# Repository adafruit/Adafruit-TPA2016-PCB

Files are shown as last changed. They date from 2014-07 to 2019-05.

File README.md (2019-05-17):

# Adafruit Stereo 2.8W Class D Audio Amplifier TPA2016 PCB
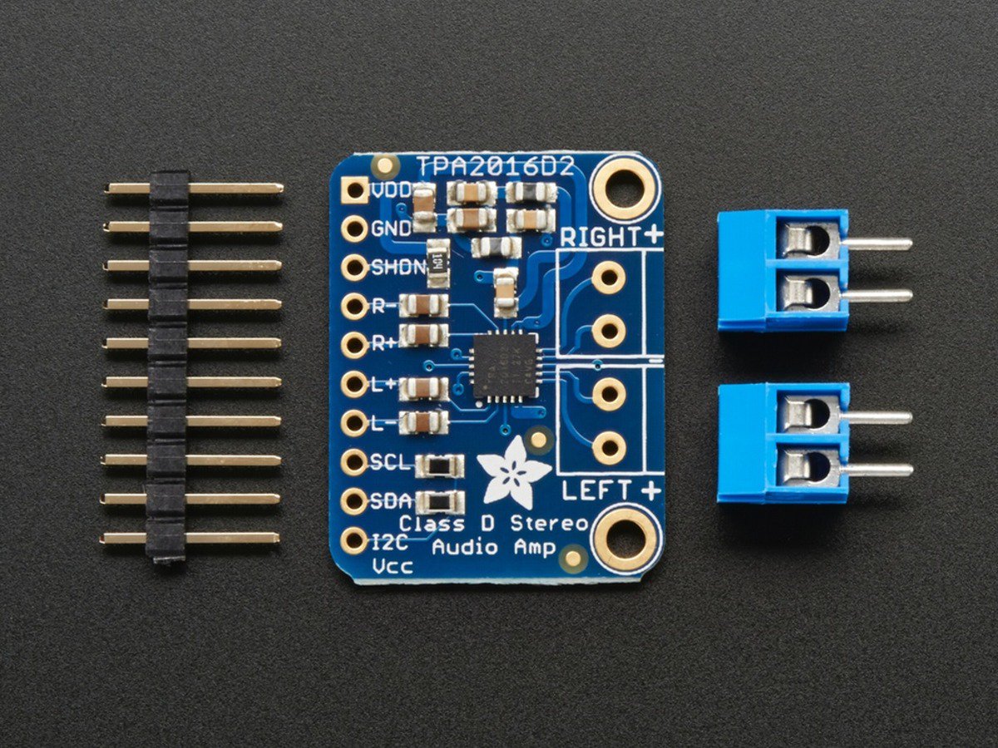
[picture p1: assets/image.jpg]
<a href="http://www.adafruit.com/products/1712"><br/>
Click here to purchase one from the Adafruit shop</a>

A mini class D with AGC and I2C control? Yes please! This incredibly small stereo amplifier is surprisingly powerful. It is able to deliver 2 x 2.8W channels into 4 ohm impedance speakers (@ 10% THD) and it has a i2c control interface as well as an AGC (automatic gain control) system to keep your audio from clipping or distorting.

If you don't want to use I2C to control it, it does start up on with 6dB gain by default and the AGC set up for most music playing. We do suggest using it with a microcontroller to configure it, however, since its quite powerful. Settings are not stored in the chip, so you'll need to adjust any gain & AGC amplification settings every time the amp is powered up.

Inside the miniature chip is a class D controller, able to run from 2.7V-5.5VDC. Since the amp is a class D, it's incredibly efficient (89% efficient when driving an 8Ω speaker at 1.5 Watt) - making it perfect for portable and battery-powered projects. It has built in thermal and over-current protection but we could barely tell if it got hot. This board is a welcome upgrade to basic "LM386" amps!

PCB files for Adafruit TPA2016 I2C Audio Amplifier PCB. The format is EagleCAD schematic and board layout: https://www.adafruit.com/products/1712

### License

Adafruit invests time and resources providing this open source design, please support Adafruit and open-source hardware by purchasing products from [Adafruit](https://www.adafruit.com)!

All text above must be included in any redistribution

Designed by Limor Fried/Ladyada for Adafruit Industries.
Creative Commons Attribution/Share-Alike, all text above must be included in any redistribution. 
See license.txt for additional information.

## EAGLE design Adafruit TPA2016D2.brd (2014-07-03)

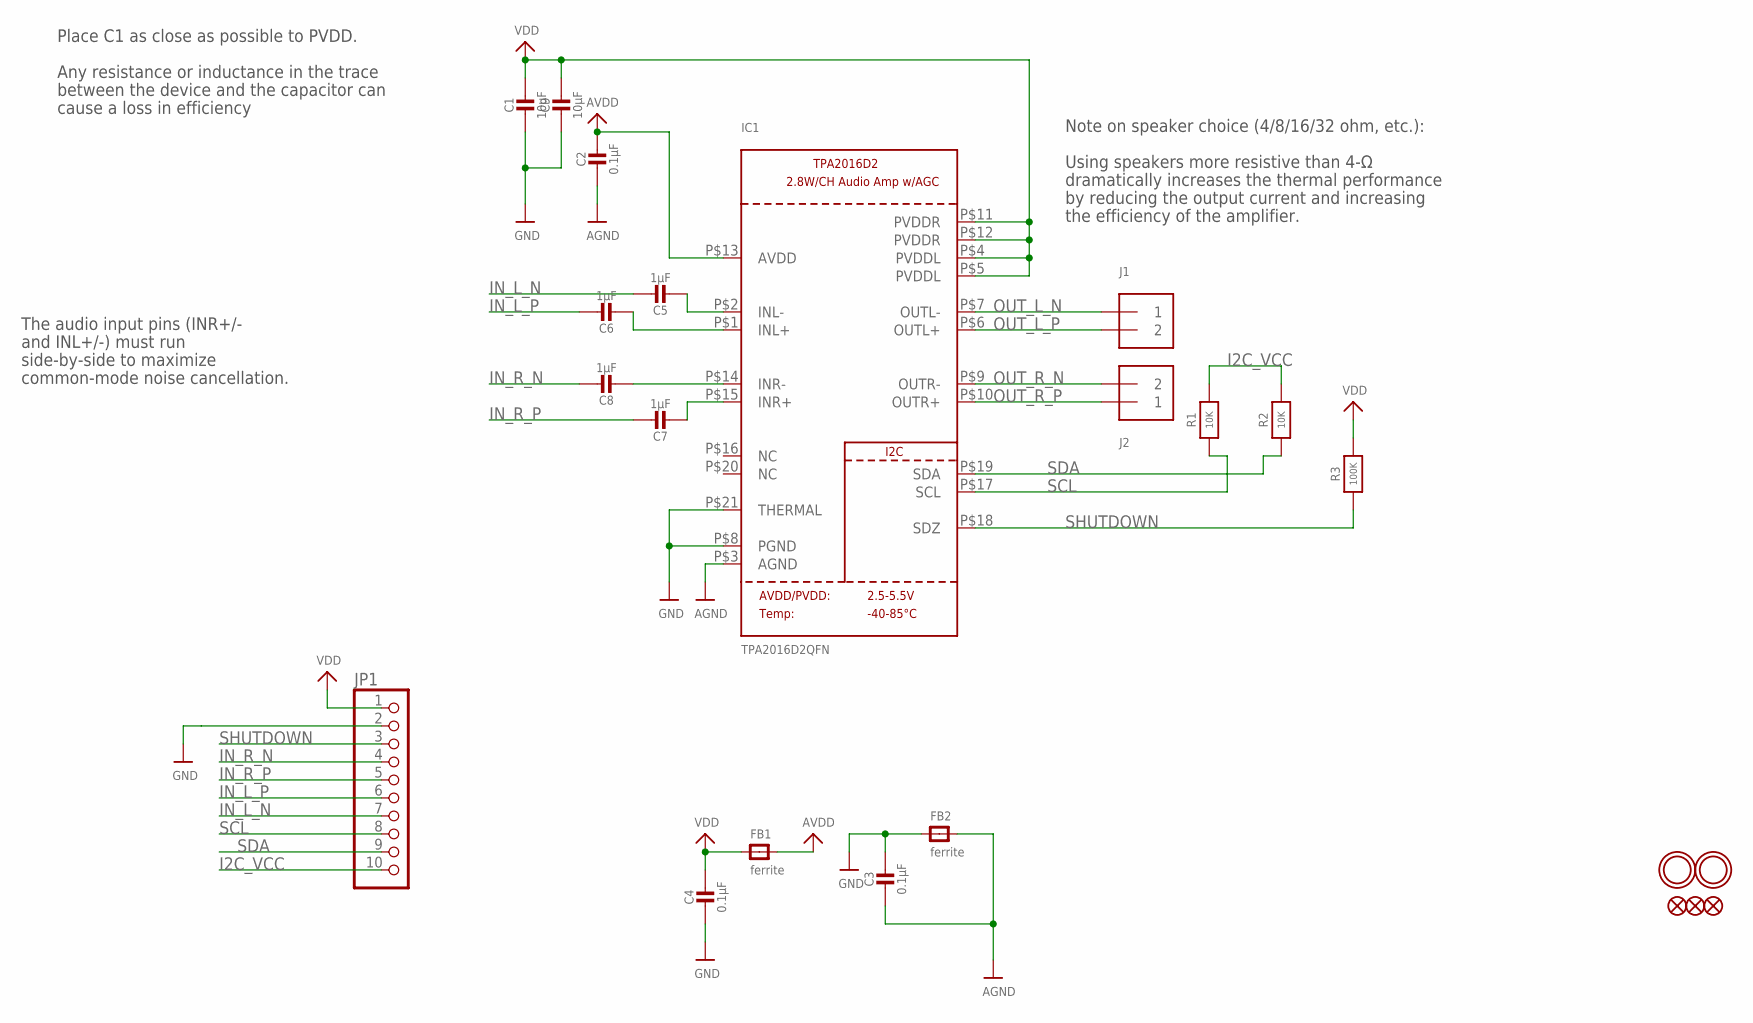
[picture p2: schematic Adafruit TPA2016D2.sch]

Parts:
C1, C9: 10µF; 0805-NO
C2, C3, C4: 0.1µF; 0805-NO
C5, C6, C7, C8: 1µF; 0805-NO
FB1, FB2: ferrite; _0805MP
FID1, FID2, FID3: FIDUCIAL""; FIDUCIAL_1MM
IC1: TPA2016D2QFN; QFN20_4MM
J1, J2: TERMBLOCK_1X2; TERMBLOCK_1X2-3.5MM
JP1: HEADER-1X1070MIL; 1X10_ROUND70
R1, R2: 10K; 0805-NO
R3: 100K; 0805-NO
U$20, U$21: MOUNTINGHOLE2.5_THICK; MOUNTINGHOLE_2.5_PLATED_THICK

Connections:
AGND: C2.2, C3.2, FB2.2, IC1.P$3 (AGND)
AVDD: C2.1, FB1.2, IC1.P$13 (AVDD)
GND: C1.2, C3.1, C4.2, C9.2, FB2.1, IC1.P$8 (PGND), IC1.P$21 (THERMAL), JP1.2
I2C_VCC: JP1.10, R1.2, R2.2
IN_L_N: C5.1, JP1.7
IN_L_P: C6.1, JP1.6
IN_R_N: C8.1, JP1.4
IN_R_P: C7.1, JP1.5
unnamed: C6.2, IC1.P$1 (INL+)
unnamed: C5.2, IC1.P$2 (INL-)
unnamed: C8.2, IC1.P$14 (INR-)
unnamed: C7.2, IC1.P$15 (INR+)
OUT_L_N: IC1.P$7 (OUTL-), J1.1
OUT_L_P: IC1.P$6 (OUTL+), J1.2
OUT_R_N: IC1.P$9 (OUTR-), J2.2
OUT_R_P: IC1.P$10 (OUTR+), J2.1
SCL: IC1.P$17 (SCL), JP1.8, R1.1
SDA: IC1.P$19 (SDA), JP1.9, R2.1
SHUTDOWN: IC1.P$18 (SDZ), JP1.3, R3.1
VDD: C1.1, C4.1, C9.1, FB1.1, IC1.P$4 (PVDDL), IC1.P$5 (PVDDL), IC1.P$11 (PVDDR), IC1.P$12 (PVDDR), JP1.1, R3.2

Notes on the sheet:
Place C1 as close as possible to PVDD.
Any resistance or inductance in the trace
between the device and the capacitor can
cause a loss in efficiency
Using speakers more resistive than 4-Ω
dramatically increases the thermal performance
by reducing the output current and increasing
the efficiency of the amplifier.
Note on speaker choice (4/8/16/32 ohm, etc.):
The audio input pins (INR+/-
and INL+/-) must run
side-by-side to maximize
common-mode noise cancellation.

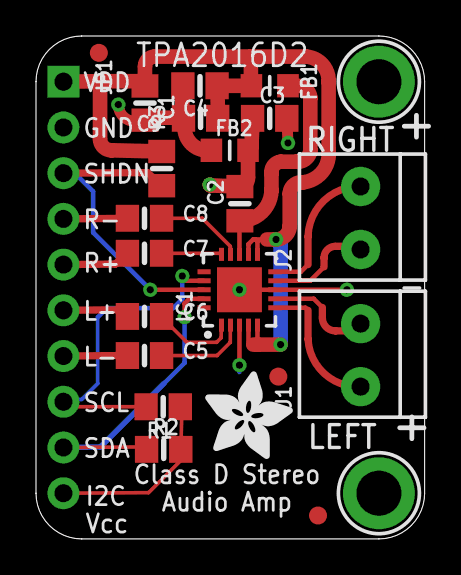
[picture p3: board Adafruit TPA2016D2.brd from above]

Board: 2 copper layers, 21.6 x 27.9 mm, 25 parts (1 on the bottom side), 20 nets.

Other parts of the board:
U$3: ADAFRUIT_5MM
U$4: ADAFRUIT_3.5MM
